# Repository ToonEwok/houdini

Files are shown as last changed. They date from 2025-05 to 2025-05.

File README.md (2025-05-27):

The Houdini is a drop-in mixbox conversion for fight sticks with ~23.5MM holes for said stick (sanwa or hori will work off the top of my head).

### Note:  
As of May 26, 2025 I am yet to get the PCB's printed and tested, if I would've known I was going to make this I would've waited before placing my order with the pcb manufacturer. At any rate this is your disclaimer that this has not technically been tested only test fit, however I am 99.9% sure it will work and will be ordering a small batch the next time I place an order for a bigger personal project I currently have.

To assemble you will need:

- 1x PCB  
- ~37 grams of the filament of your choice for the following parts:  
  - 1x houdini_top  
  - 1x houdini_base  
  - 1x houdini_screw  
- 4x choc v1 switches  
- 4x choc v1 hotswaps (PG1350)  
- 6x M2x4MM screws  
- 6x M2 brass inserts, the dimensions of the ones I used are M2x3x3.5  
- Really any wire, 22 AWG is the typical gauge for fight sticks  

Lastly, if you are using this to plug directly into an existing wiring harness I recommend getting a female 2.54 pitch 5 pin connector and some 2.54 male-to-male pins (something like these - https://www.digikey.com/en/products/detail/harwin-inc/D01-9923246/3918909) that should allow you to plug into your existing harness with no issue.

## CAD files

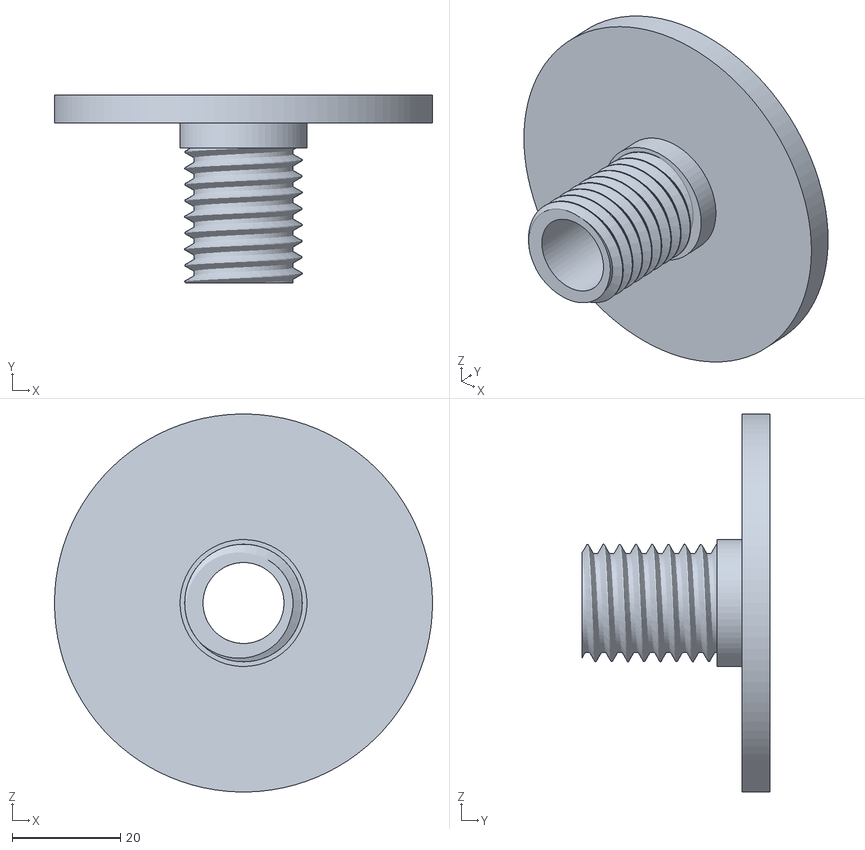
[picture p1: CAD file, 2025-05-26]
case/houdini-base.stl
70.0 x 34.8 x 70.0

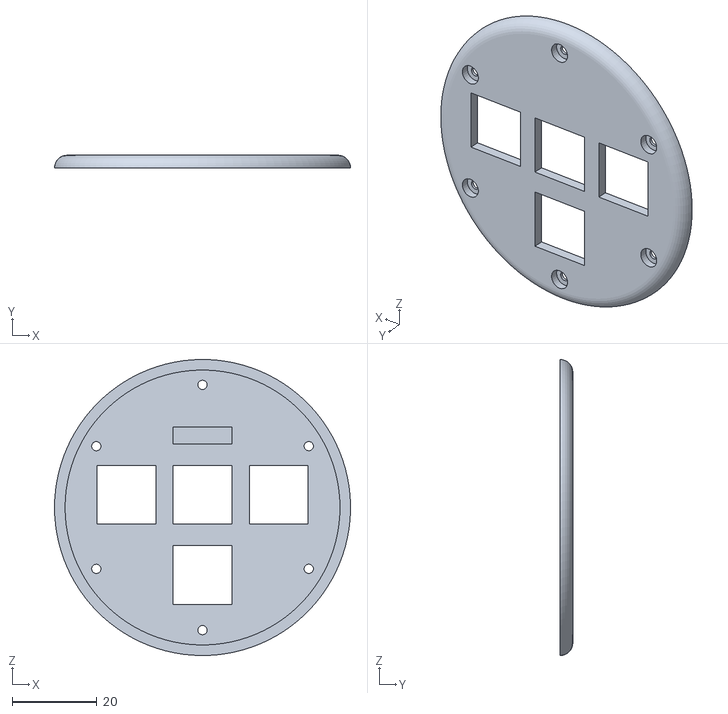
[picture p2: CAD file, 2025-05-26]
case/houdini-top.stl
70.0 x 3.00 x 70.0

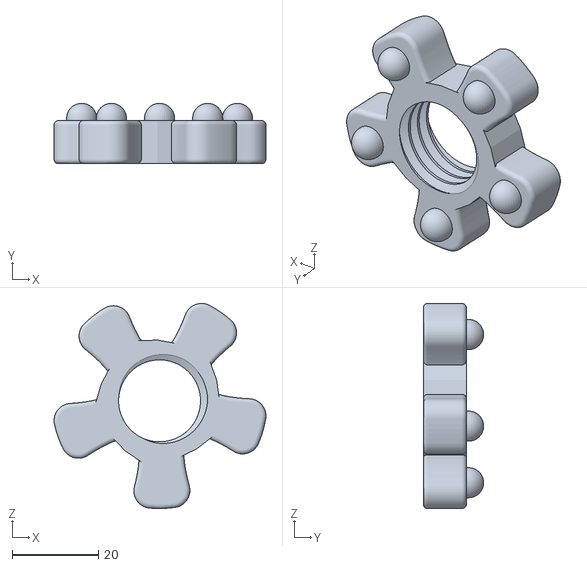
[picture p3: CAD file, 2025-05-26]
case/houdini-screw.stl
49.2 x 14.0 x 47.6

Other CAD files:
case/houdini v7.f3d

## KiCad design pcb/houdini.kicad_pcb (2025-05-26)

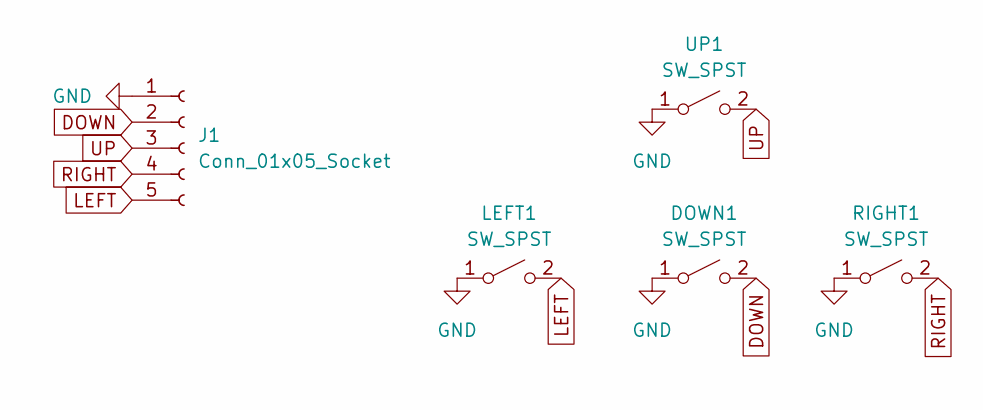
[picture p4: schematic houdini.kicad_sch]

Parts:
DOWN1: SW_SPST; Kailh_socket_PG1350
J1: Conn_01x05_Socket; PinSocket_1x05_P2.54mm_Vertical
LEFT1: SW_SPST; Kailh_socket_PG1350
RIGHT1: SW_SPST; Kailh_socket_PG1350
UP1: SW_SPST; Kailh_socket_PG1350

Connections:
DOWN: DOWN1.2 (B), J1.2
GND: DOWN1.1 (A), J1.1, LEFT1.1 (A), RIGHT1.1 (A), UP1.1 (A)
LEFT: J1.5, LEFT1.2 (B)
RIGHT: J1.4, RIGHT1.2 (B)
UP: J1.3, UP1.2 (B)

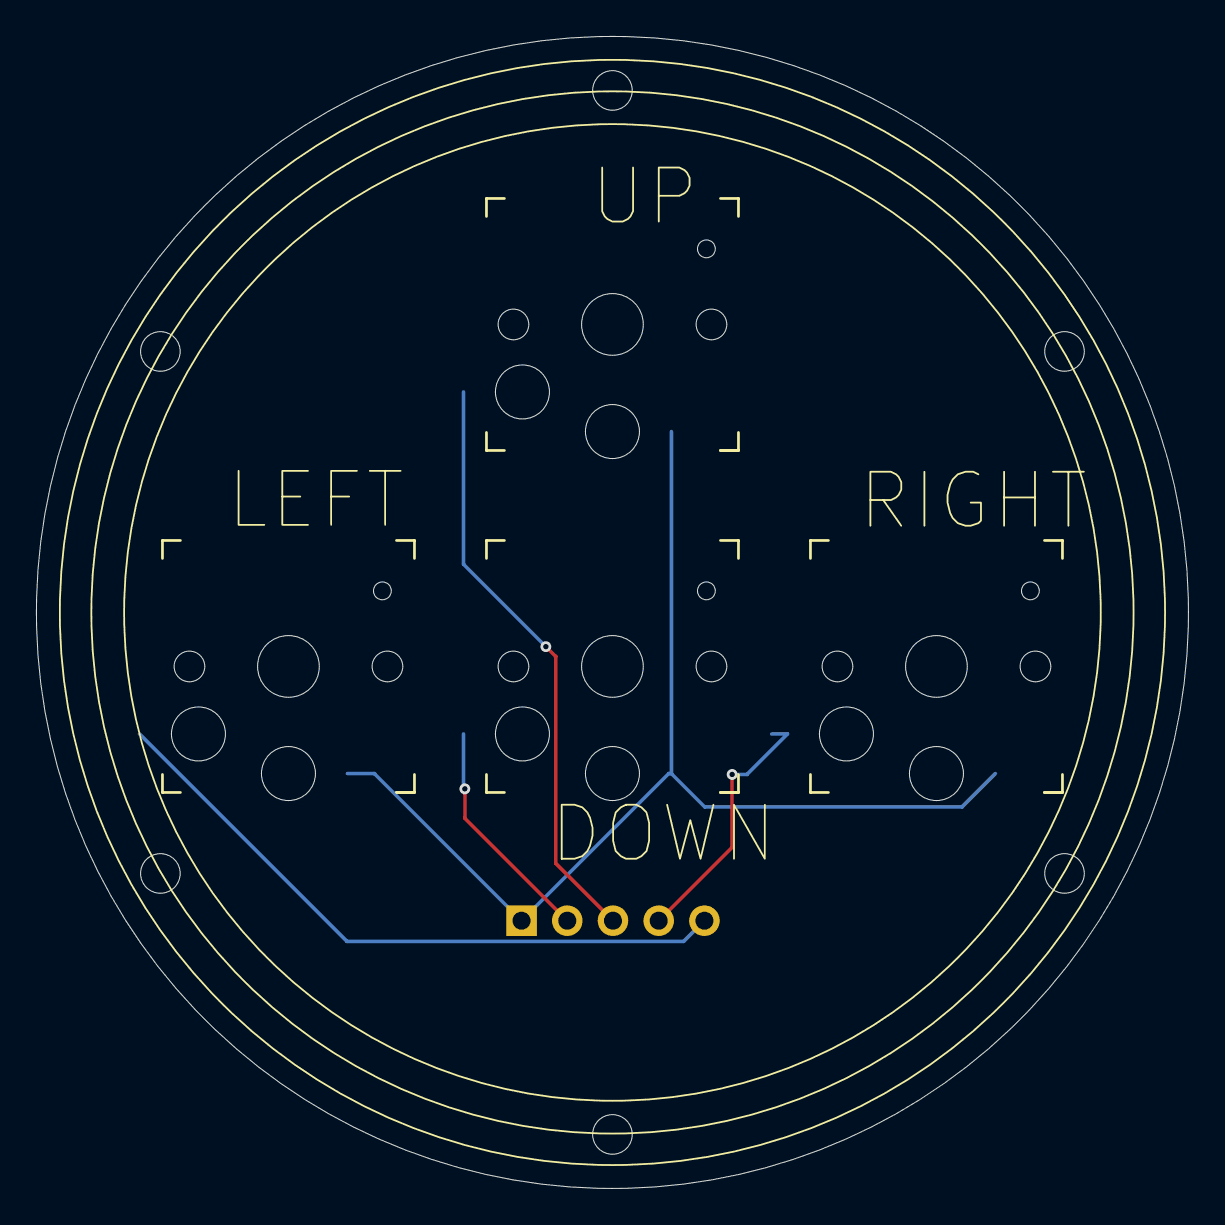
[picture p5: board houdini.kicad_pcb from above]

Board: 2 copper layers, 64.0 x 64.0 mm, 5 parts (1 on the bottom side), 5 nets.
